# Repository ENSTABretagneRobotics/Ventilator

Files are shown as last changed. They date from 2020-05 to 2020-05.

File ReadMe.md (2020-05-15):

# High flow oxygenation and ventilator prototype

This repository contains the software and CAD parts of a simple ventilator prototype made at ENSTA Bretagne in April-May 2020, with the help of Pr E. L'Her from Brest CHRU. Details on the design are available [here](https://www.ensta-bretagne.fr/lebars/Share/ventilator_prototype.pdf). The demo of the high flow oxygenation mode can be seen [is this video](https://youtu.be/vLqbTjcoQs8), the patient-triggered assistance mode is tested [there](https://youtu.be/5zMtCWrAtUk), and other random tests are made [here](https://youtu.be/ZAll08g8yRg).

Ventilator picture

See [this document](https://www.ensta-bretagne.fr/lebars/Share/ventilator_devices.pdf) for more information about the electronics architecture, check the configuration instructions in the top of `main.py` and run the code with `sudo -E python3 main.py & python3 gui.py`.

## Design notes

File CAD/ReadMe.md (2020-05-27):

It is possible to view the full CAD model using this link: https://autode.sk/3bMTDJe

The pieces are separated by the method of production into:
- To print
- To machine

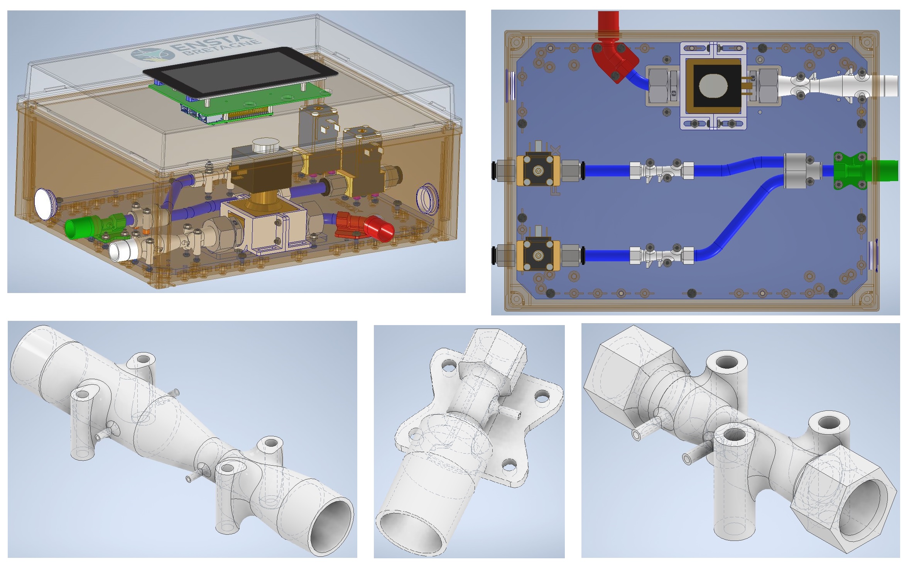
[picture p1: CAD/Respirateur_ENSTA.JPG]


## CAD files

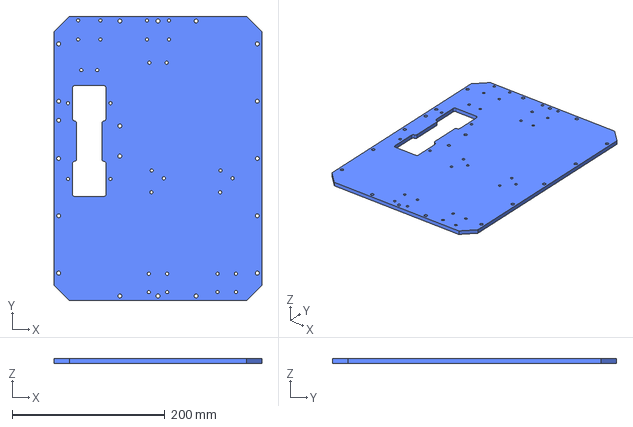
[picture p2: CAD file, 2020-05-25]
CAD/ToMachine/Base_Sheet.stp
271.8 x 371.8 x 6.00 mm

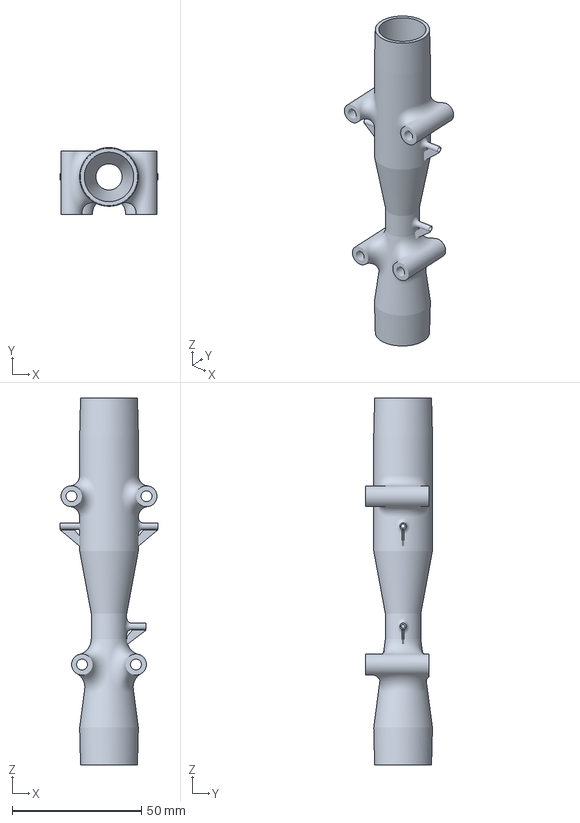
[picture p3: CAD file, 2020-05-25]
CAD/ToPrint/HighDefNozzle/3MF/UM3E_Venturi_1.5_Out.3mf
37.7 x 25.9 x 141.8 mm

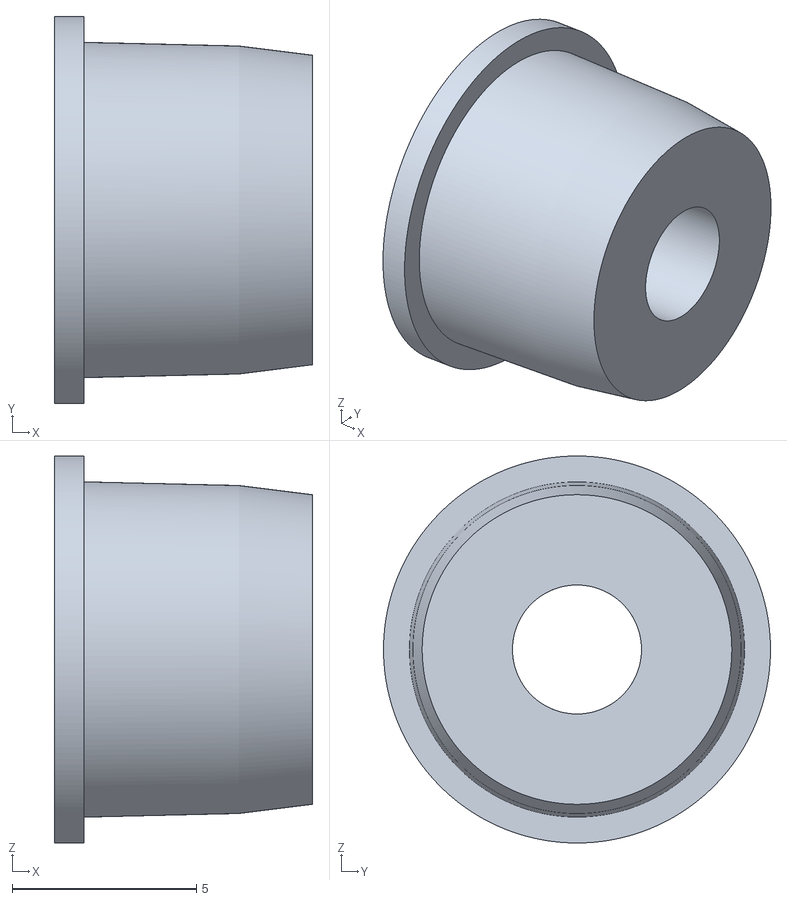
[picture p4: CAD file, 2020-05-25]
CAD/ToPrint/HighDefNozzle/STL/Orifice_3.50mm.stl
7.00 x 10.5 x 10.5

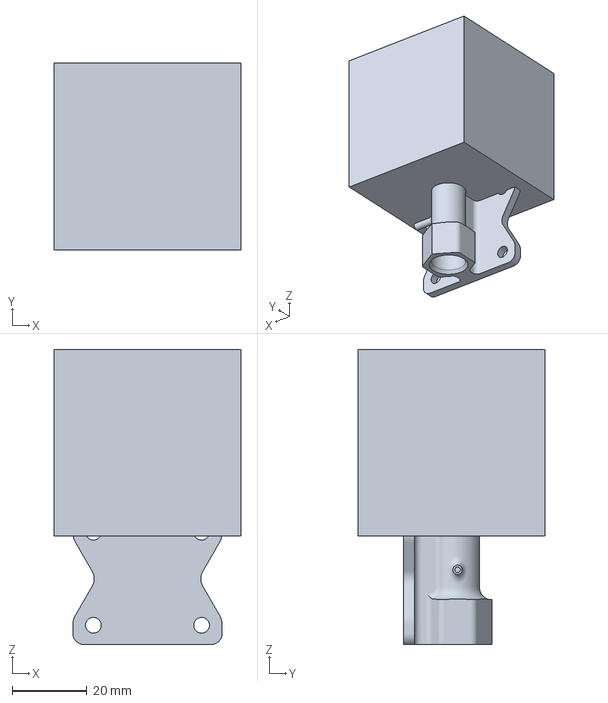
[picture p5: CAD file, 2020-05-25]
CAD/ToPrint/NormalNozzle/3MF/Adapter_12x22mm_v2.3mf
50.0 x 50.0 x 79.0 mm

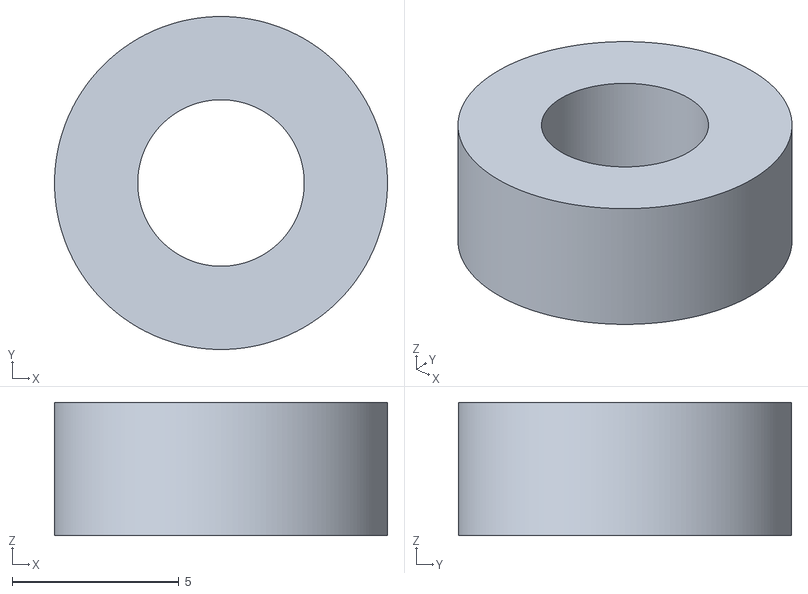
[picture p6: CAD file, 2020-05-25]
CAD/ToPrint/NormalNozzle/STL/Spacer_V2.stl
10.0 x 10.0 x 4.00

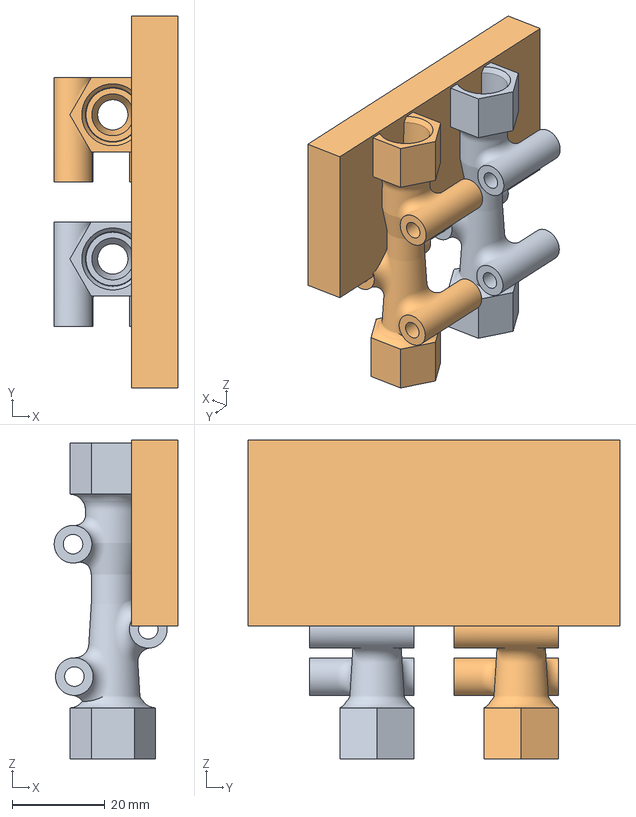
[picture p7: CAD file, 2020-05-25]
CAD/ToPrint/HighDefNozzle/3MF/UM3E_Venturi_1.3c_2x.3mf
26.6 x 80.0 x 68.6 mm
Venturi_1.3c.stl
Venturi_1.3c.stl(1)

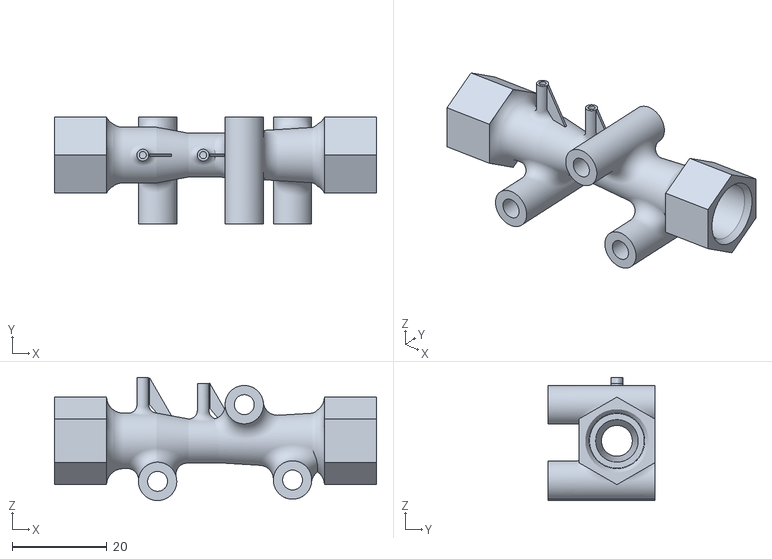
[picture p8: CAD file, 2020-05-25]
CAD/ToPrint/HighDefNozzle/STL/Venturi_1.3c.stl
67.9 x 22.5 x 26.0

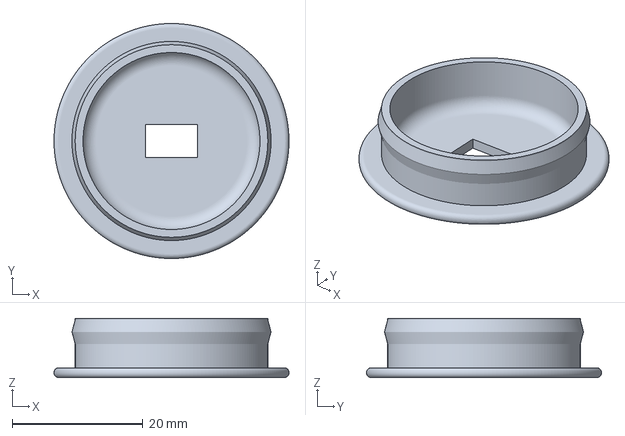
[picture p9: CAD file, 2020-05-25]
CAD/ToPrint/NormalNozzle/3MF/UM3E_Tap_Box_V2.3mf
36.0 x 36.0 x 9.07 mm

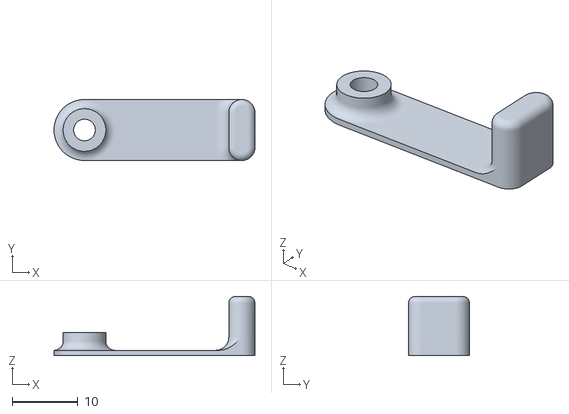
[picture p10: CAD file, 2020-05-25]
CAD/ToPrint/NormalNozzle/STL/Screen-Locker_V2.stl
30.6 x 9.30 x 9.00

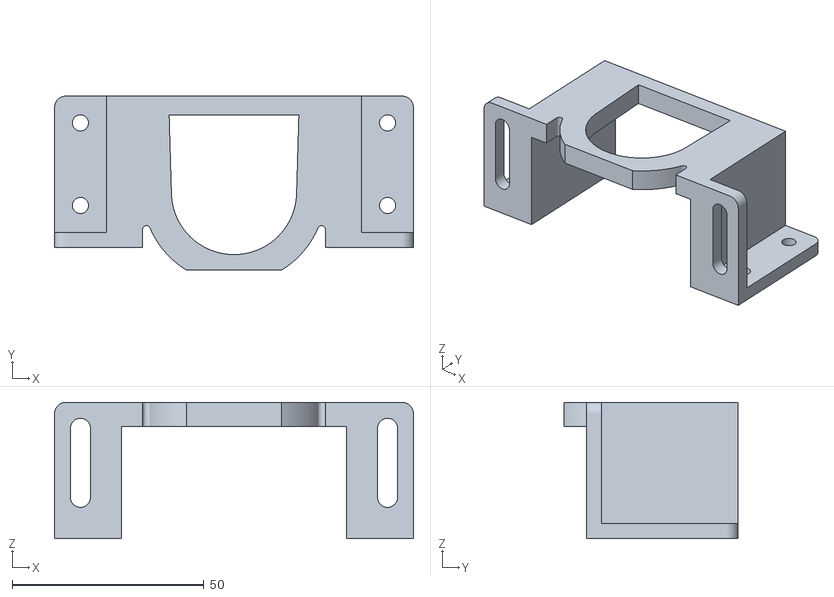
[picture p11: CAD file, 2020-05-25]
CAD/ToPrint/NormalNozzle/STL/SCB210C035_Support.stl
93.5 x 45.3 x 35.5

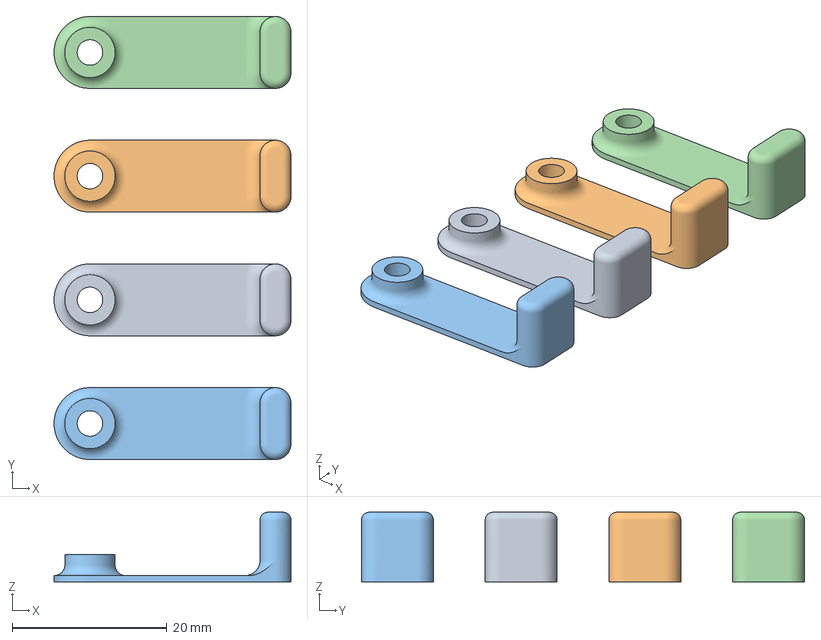
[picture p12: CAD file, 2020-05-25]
CAD/ToPrint/NormalNozzle/3MF/UM3E_Screen-Locker_V2.3mf
30.6 x 57.3 x 9.00 mm
Screen-Locker_V2.stl
Screen-Locker_V2.stl(1)
Screen-Locker_V2.stl(2)
Screen-Locker_V2.stl(3)

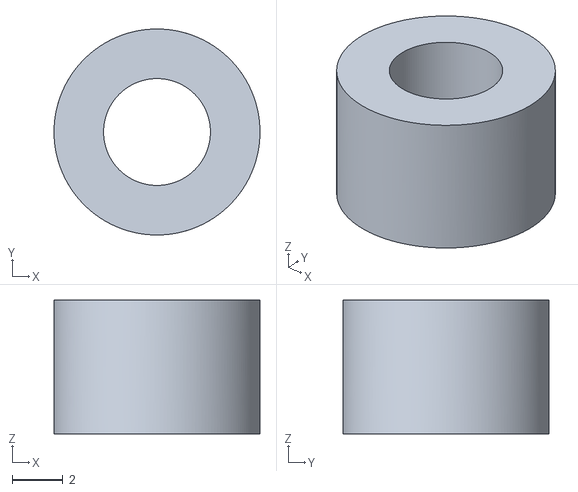
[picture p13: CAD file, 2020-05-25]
CAD/ToPrint/NormalNozzle/STL/Ring_5.25mm.stl
8.10 x 8.10 x 5.25

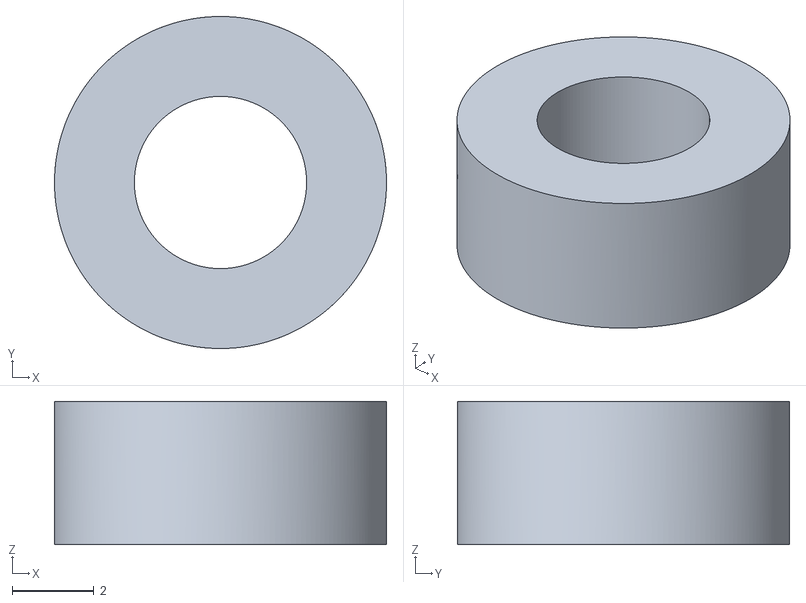
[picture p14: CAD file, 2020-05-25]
CAD/ToPrint/NormalNozzle/STL/Ring_3.5mm.stl
8.10 x 8.10 x 3.50

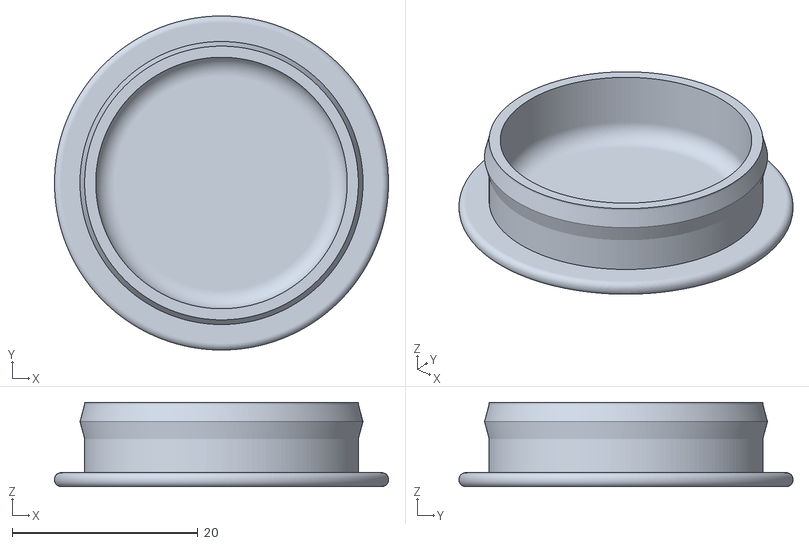
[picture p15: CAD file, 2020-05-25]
CAD/ToPrint/NormalNozzle/STL/Tap_Box.stl
36.0 x 36.0 x 9.07

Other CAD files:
CAD/ToPrint/HighDefNozzle/3MF/UM3E_Orifice_3.50mm.3mf
CAD/ToPrint/HighDefNozzle/STL/Venturi_1.5_Out.stl
CAD/ToPrint/NormalNozzle/3MF/UM3E_Spacer_V2.3mf
CAD/ToPrint/NormalNozzle/STL/Adapter_12x22mm_45deg.stl
CAD/ToPrint/NormalNozzle/STL/Adapter_12x22mm_v2.stl

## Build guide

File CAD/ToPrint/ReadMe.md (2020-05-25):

The printed parts were obtained using the FDM method through an Ultimaker 3 Extended printer using Ultimaker CURA as the slicer.

This folder contains the parts that have to be 3D printed. They are divided into two types depending on the required accuracy:
- Normal nozzle diameter: 0.40 mm
- High-definition nozzle diameter: 0.25 mm

ATTENTION: STL files do not show the parts in the correct printing orientation. To know the correct part orientation and printing configurations check 3MF files in CURA slicer.

(CURA slicer is available in https://ultimaker.com/software/ultimaker-cura)

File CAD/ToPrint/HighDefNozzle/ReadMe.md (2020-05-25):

High-definition diameter: 0.20 or 0.25 mm

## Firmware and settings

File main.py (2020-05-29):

#!/usr/bin/python

from __future__ import division, print_function
import ms5837 # From https://github.com/bluerobotics/ms5837-python
import rsc # From https://github.com/tin-/ascp
import hsc
import numpy as np
import math
import sys
import os
import time
import threading
import signal
from timeit import default_timer as timer
from common import *

#sudo apt-get install python-smbus python-spidev python-pyqtgraph
# or
#sudo pip install smbus
#sudo pip install spidev
#sudo pip install pyqtgraph
# if it did not work and/or try also with python3 and pip3.
# Raspberry Pi 4 configuration (GPIO that will be used : 0 for PWM expiration 
# valve, 1, 2, 3, 14, 15 for SPI3 Honeywell RSC for flow (expiration), 4, 5
# for I2C3 Honeywell HSC (expiration)[, Bar02 (room), 6 for digital
# output inspiration valve], 7, 8, 9, 10, 11 for SPI0 Honeywell RSC for flow 
# (air), 12, 13 for PWM O2 and air valves, 16 for 
# digital input UP button, 17 for digital input DOWN button, 18, 19, 20, 21, 27
# for SPI6 Honeywell RSC for flow (O2), 22, 23 for I2C6 Honeywell HSC 
# (inspiration)[, Bar02 (inspiration), RTC clock], 24 for digital input
# SELECT button, 25 for POWER button, 26 for PWM buzzer)
#sudo nano /boot/config.txt
# Add/modify in /boot/config.txt (SPI6 might appear as 4, check /dev...)
#enable_uart=0
#dtparam=i2c_arm=on
#dtoverlay=i2c1,pins_44_45
#dtoverlay=i2c-gpio,bus=3,i2c_gpio_delay_us=1,i2c_gpio_sda=4,i2c_gpio_scl=5
#dtoverlay=i2c-gpio,bus=6,i2c_gpio_delay_us=1,i2c_gpio_sda=22,i2c_gpio_scl=23
#dtparam=spi=on
#dtoverlay=spi3-2cs,cs0_pin=14,cs1_pin=15
#dtoverlay=spi6-2cs
#dtoverlay=gpio-shutdown,gpio_pin=25,active_low=1,gpio_pull=up
# Disable touch screen sleep (see https://www.raspberrypi.org/forums/viewtopic.php?t=255163)
#sudo nano /etc/xdg/lxsession/LXDE-pi/autostart
#@xset s off
#@xset -dpms
# Then reboot and
#sudo -E python main.py & python gui.py

# Parameters
###############################################################################
# User parameters
mode = 0 # 0 : ventilator, 1 : ventilator in assistance mode, 2 : only O2:Air mix
flow_control = 40 # In L/min, >= flow_control_max means no limit...
O2_percent = 50 # In %, 0 means no pure O2 will be added to air, 100 means no air, ignored if flow_control >= flow_control_max...
ramp = 10 # In % of the inspiration time, to increase progressively flow and avoid pressure peak just due to strong and fast flow...
Ppeak = 30 # In mbar (= approx. cmH2O)
PEEP = 5 # In mbar (= approx. cmH2O)
respi_rate = 20 # In breaths/min
inspi_percent = 33 # Inspiration time in % of cycle time
# User advanced parameters
PEEP_dec_rate = 100 # In %, to limit the maximum expiration flow before reaching the PEEP
PEEP_tuning = 100 # In %, to tune the expiration flow when maintaining the PEEP
Fl_PEEP = 100 # In % of flow_control, to help detecting inspiration after reaching the PEEP
O2_PEEP = 100 # In % of O2_percent, to help detecting inspiration after reaching the PEEP
PEEP_inspi_detection_delta = 2.5 # In mbar (= approx. cmH2O)
vol_inspi_detection_delta = 15 # In ml
inspi_detection_delta_duration = 250 # In ms
flow_thresh = 4 # To avoid noise in volume computation, in L/min
# Advanced parameters
mode_step = 1
mode_min = 0
mode_max = 2
flow_control_step = 2
flow_control_min = 0
flow_control_max = 300
O2_percent_step = 1
O2_percent_min = 0
O2_percent_max = 100
ramp_step = 1
ramp_min = 0
ramp_max = 100
Ppeak_step = 1
Ppeak_min = 0
Ppeak_max = 150
PEEP_step = 1
PEEP_min = 0
PEEP_max = 150
respi_rate_step = 1
respi_rate_min = 1
respi_rate_max = 100
inspi_percent_step = 1
inspi_percent_min = 0
inspi_percent_max = 100
PEEP_dec_rate_step = 2
PEEP_dec_rate_min = 1
PEEP_dec_rate_max = 100
PEEP_tuning_step = 2
PEEP_tuning_min = 1
PEEP_tuning_max = 100
Fl_PEEP_step = 5
Fl_PEEP_min = 0
Fl_PEEP_max = 1000
O2_PEEP_step = 5
O2_PEEP_min = 0
O2_PEEP_max = 1000
PEEP_inspi_detection_delta_step = 0.1
PEEP_inspi_detection_delta_min = 0
PEEP_inspi_detection_delta_max = 50
vol_inspi_detection_delta_step = 1
vol_inspi_detection_delta_min = 0
vol_inspi_detection_delta_max = 100
inspi_detection_delta_duration_step = 10
inspi_detection_delta_duration_min = 0
inspi_detection_delta_duration_max = 1000
flow_thresh_step = 0.25
flow_thresh_min = 0
flow_thresh_max = 50
enable_alarms = True
enable_buzzer = True
enable_p_ms5837 = False
enable_p0_ms5837 = False
enable_p_inspi_hsc = True
enable_p_expi_hsc = True
enable_air_rsc = True
enable_expi_rsc = True
enable_O2_rsc = True
rho0_air = 1.292 # In kg/m3 at 0 C
rho0_expi = 1.292 # In kg/m3 at 0 C
#rho0_O2 = 1.428 # In kg/m3 at 0 C
rho0_O2 = 1.292 # In kg/m3 at 0 C
#R1_air = 0.019100/2.0 # In m
R1_air = 0.009000/2.0 # In m
#R2_air = 0.011651/2.0 # In m
R2_air = 0.006500/2.0 # In m
R1_expi = 0.019100/2.0 # In m
#R1_expi = 0.009000/2.0 # In m
#R2_expi = 0.011651/2.0 # In m
R2_expi = 0.010100/2.0 # In m
#R2_expi = 0.006500/2.0 # In m
#R2_expi = 0.008000/2.0 # In m
#R1_O2 = 0.019100/2.0 # In m
R1_O2 = 0.009000/2.0 # In m
#R2_O2 = 0.011651/2.0 # In m
R2_O2 = 0.006500/2.0 # In m
rho_air = rho0_air
rho_expi = rho0_expi
rho_O2 = rho0_O2
A1_air = math.pi*R1_air**2 # In m2
A2_air = math.pi*R2_air**2 # In m2
A1_expi = math.pi*R1_expi**2 # In m2
A2_expi = math.pi*R2_expi**2 # In m2
A1_O2 = math.pi*R1_O2**2 # In m2
A2_O2 = math.pi*R2_O2**2 # In m2
speed_rsc = 175 # In SPS
delay_rsc = 0.010 # In s
coef_filter_rsc = 0.95
nb_count_auto_zero_filter_rsc = 100 # 100
nb_count_offset_filter_rsc = 100 # 100
valves_pwm_freq = 1200 # In Hz
valves_init = 50
valves_closed = 10 # Should be <= 99
valves_delay = 0.020 # In s
P_err = 50 # In mbar (= approx. cmH2O)
P_absolute_min = -10 # In mbar (= approx. cmH2O)
P_absolute_max = 159 # In mbar (= approx. cmH2O)
coef_offset_filter_flow = 0.99
coef_filter_flow = 0.0
positive_filter_flow = True
flow_control_PEEP = flow_control*Fl_PEEP*0.01
flow_control_pressure_excess = flow_control
flow_control_PEEP_pressure_excess = flow_control_PEEP
err_pressure_PEEP_thresh = 0.5 # In mbar (= approx. cmH2O)
coef_PEEP_pressure_control_valve_expi = 2.0
coef_PEEP_flow_control_valve_expi = 0.0
coef_PEEP_pressure_control_valve_air = 0.0
coef_PEEP_pressure_control_valve_O2 = 0.0
coef_PEEP_flow_control_valve_air = 2.0
coef_PEEP_flow_control_valve_O2 = 2.0
coef_pressure_excess = 8.0
coef_flow_control_valve_air = 2.0
coef_flow_control_valve_O2 = 2.0
debug = False
###############################################################################

alarms = 0

os.system('pigpiod -x 0x0FFFFFFF') # To be able to use GPIO 0 and 1 also...
time.sleep(0.2)
import pigpio
pi = pigpio.pi()
if not pi.connected:
    print('Unable to connect to pigpio')
    exit(1)
print('pigpio connected')

# Software PWM init for buzzer
if enable_buzzer:
    buz_pin = 26
    pi.set_mode(buz_pin, pigpio.OUTPUT)
    pi.set_PWM_frequency(buz_pin, 4000)
    pi.set_PWM_dutycycle(buz_pin, 128) # Startup beep...

# Other PWM init
valve_air_pin = 12
if (flow_control < flow_control_max): valve_air_val_max = valves_init # Min > 0 to not always disable proportional valves control...
else: valve_air_val_max = 100
valve_air_val_max_closed = valve_air_val_max
valve_air_val_max_PEEP = valves_init
valve_air_val = 0
valve_air_val = min(100, max(0, valve_air_val))
valve_O2_pin = 13
if (flow_control < flow_control_max): valve_O2_val_max = valves_init # Min > 0 to not always disable proportional valves control...
else: valve_O2_val_max = 100
valve_O2_val_max_closed = valve_O2_val_max
valve_O2_val_max_PEEP = valves_init
valve_O2_val = 0
valve_O2_val = min(100, max(0, valve_O2_val))
pi.set_mode(valve_air_pin, pigpio.OUTPUT)
pi.set_PWM_frequency(valve_air_pin, valves_pwm_freq)
pi.set_PWM_dutycycle(valve_air_pin, int(min(255, max(0, 255*valve_air_val/100))))
pi.set_mode(valve_O2_pin, pigpio.OUTPUT)
pi.set_PWM_frequency(valve_O2_pin, valves_pwm_freq)
pi.set_PWM_dutycycle(valve_O2_pin, int(min(255, max(0, 255*valve_O2_val/100))))

# Digital outputs (valves)
valve_expi_pin = 0
valve_expi_val_max_PEEP = PEEP_dec_rate
valve_expi_val = 0
valve_expi_val = min(100, max(0, valve_expi_val))
pi.set_mode(valve_expi_pin, pigpio.OUTPUT)
pi.set_PWM_frequency(valve_expi_pin, valves_pwm_freq)
pi.set_PWM_dutycycle(valve_expi_pin, int(min(255, max(0, 255-255*valve_expi_val/100)))) 

# Digital inputs (buttons)
select = -1 # Index of the selected parameter that should be changed by up/down buttons
parameters = ['mode', 'flow_control', 'O2_percent', 'ramp', 'Ppeak', 'PEEP', 'respi_rate', 'inspi_percent', 
              'PEEP_dec_rate', 'PEEP_tuning', 'Fl_PEEP', 'O2_PEEP', 'PEEP_inspi_detection_delta', 'vol_inspi_detection_delta', 'inspi_detection_delta_duration', 'flow_thresh']
select_button_pin = 24
pi.set_mode(select_button_pin, pigpio.INPUT)
pi.set_pull_up_down(select_button_pin, pigpio.PUD_UP)
select_button_val = pi.read(select_button_pin)
select_button_val_prev = select_button_val
up_button_pin = 16
pi.set_mode(up_button_pin, pigpio.INPUT)
pi.set_pull_up_down(up_button_pin, pigpio.PUD_UP)
up_button_val = pi.read(up_button_pin)
up_button_val_prev = up_button_val
down_button_pin = 17
pi.set_mode(down_button_pin, pigpio.INPUT)
pi.set_pull_up_down(down_button_pin, pigpio.PUD_UP)
down_button_val = pi.read(down_button_pin)
down_button_val_prev = down_button_val

# Bar02, HSC
if enable_p_ms5837:
    p_ms5837 = ms5837.MS5837_02BA(bus = 6)
    try:
        if not p_ms5837.init():
            print('P sensor could not be initialized')
            time.sleep(0.1)
            if not p_ms5837.init():
                print('P sensor could not be initialized')
                exit(1)
    except:
        print('P sensor could not be initialized')
        time.sleep(0.1)
        if not p_ms5837.init():
            print('P sensor could not be initialized')
            exit(1)
if enable_p0_ms5837:
    p0_ms5837 = ms5837.MS5837_02BA(bus = 3)
    try:
        if not p0_ms5837.init():
            print('P0 sensor could not be initialized')
            time.sleep(0.1)
            if not p0_ms5837.init():
                print('P0 sensor could not be initialized')
                exit(1)
    except:
        print('P0 sensor could not be initialized')
        time.sleep(0.1)
        if not p0_ms5837.init():
            print('P0 sensor could not be initialized')
            exit(1)
if enable_p_inspi_hsc:
    try:
        p_inspi_hsc = hsc.HHSC(bus = 6, addr = 0x48, min_pressure = -160.0, max_pressure = 160.0, unit = 'mbar', transfer = 'A')
    except:
        print('HSC I sensor could not be initialized')
        time.sleep(0.1)
        try:
            p_inspi_hsc = hsc.HHSC(bus = 6, addr = 0x48, min_pressure = -160.0, max_pressure = 160.0, unit = 'mbar', transfer = 'A')
        except:
            print('HSC I sensor could not be initialized')
            exit(1)
if enable_p_expi_hsc:
    try:
        p_expi_hsc = hsc.HHSC(bus = 3, addr = 0x48, min_pressure = -160.0, max_pressure = 160.0, unit = 'mbar', transfer = 'A')
    except:
        print('HSC E sensor could not be initialized')
        time.sleep(0.1)
        try:
            p_expi_hsc = hsc.HHSC(bus = 3, addr = 0x48, min_pressure = -160.0, max_pressure = 160.0, unit = 'mbar', transfer = 'A')
        except:
            print('HSC E sensor could not be initialized')
            exit(1)
# The very first pressure measurements might be wrong...
i = 0
while (i < 5):
    if enable_p_ms5837:
        if not p_ms5837.read(ms5837.OSR_256):
            print('P sensor read failed!')
            time.sleep(0.1)
    if enable_p0_ms5837:
        if not p0_ms5837.read(ms5837.OSR_256):
            print('P0 sensor read failed!')
            time.sleep(0.1)
    if enable_p_inspi_hsc:
        try:
            p_diff_inspi_hsc, temp_inspi_hsc = p_inspi_hsc.read()
        except:
            print('HSC I sensor read failed!')
            time.sleep(0.1)
    if enable_p_expi_hsc:
        try:
            p_diff_expi_hsc, temp_expi_hsc = p_expi_hsc.read()
        except:
            print('HSC E sensor read failed!')
            time.sleep(0.1)
    i = i+1

# Honeywell RSC
pressure_air, temperature_air, flow_air, flow_filtered_air, vol_air, pressure_offset_air, flow_offset_air = 0, 25, 0, 0, 0, 0, 0
pressure_expi, temperature_expi, flow_expi, flow_filtered_expi, vol_expi, pressure_offset_expi, flow_offset_expi = 0, 25, 0, 0, 0, 0, 0
pressure_O2, temperature_O2, flow_O2, flow_filtered_O2, vol_O2, pressure_offset_O2, flow_offset_O2 = 0, 25, 0, 0, 0, 0, 0
if enable_air_rsc: 
    flow_air_rsc = rsc.HRSC(spi_bus = 0)
    flow_air_rsc.sensor_info()
    flow_air_rsc.reset()
if enable_expi_rsc: 
    flow_expi_rsc = rsc.HRSC(spi_bus = 3)
    flow_expi_rsc.sensor_info()
    flow_expi_rsc.reset()
if enable_O2_rsc: 
    flow_O2_rsc = rsc.HRSC(spi_bus = 4)
    flow_O2_rsc.sensor_info()
    flow_O2_rsc.reset()
time.sleep(0.005)
if enable_air_rsc: 
    flow_air_rsc.adc_configure()
    flow_air_rsc.set_speed(speed_rsc)
if enable_expi_rsc: 
    flow_expi_rsc.adc_configure()
    flow_expi_rsc.set_speed(speed_rsc)
if enable_O2_rsc: 
    flow_O2_rsc.adc_configure()
    flow_O2_rsc.set_speed(speed_rsc)
time.sleep(0.005)
if enable_air_rsc: 
    flow_air_rsc.pressure_request()
if enable_expi_rsc: 
    flow_expi_rsc.pressure_request()
if enable_O2_rsc: 
    flow_O2_rsc.pressure_request()
time.sleep(delay_rsc)
if enable_air_rsc: 
    raw_pressure_air = flow_air_rsc.pressure_reply()
    flow_air_rsc.temperature_request()
if enable_expi_rsc: 
    raw_pressure_expi = flow_expi_rsc.pressure_reply()
    flow_expi_rsc.temperature_request()
if enable_O2_rsc: 
    raw_pressure_O2 = flow_O2_rsc.pressure_reply()
    flow_O2_rsc.temperature_request()
time.sleep(delay_rsc)
if enable_air_rsc: 
    raw_temperature_air = flow_air_rsc.temperature_reply()
    raw_zero_pressure_air = raw_pressure_air
    raw_zero_temperature_air = raw_temperature_air
    pressure_air, temperature_air = flow_air_rsc.comp_readings(raw_pressure_air, raw_temperature_air)
    pressure_air = flow_air_rsc.conv_pressure_to_mbar(pressure_air)
    pressure_offset_air = pressure_air
if enable_expi_rsc: 
    raw_temperature_expi = flow_expi_rsc.temperature_reply()
    raw_zero_pressure_expi = raw_pressure_expi
    raw_zero_temperature_expi = raw_temperature_expi
    pressure_expi, temperature_expi = flow_expi_rsc.comp_readings(raw_pressure_expi, raw_temperature_expi)
    pressure_expi = flow_expi_rsc.conv_pressure_to_mbar(pressure_expi)
    pressure_offset_expi = pressure_expi
if enable_O2_rsc: 
    raw_temperature_O2 = flow_O2_rsc.temperature_reply()
    raw_zero_pressure_O2 = raw_pressure_O2
    raw_zero_temperature_O2 = raw_temperature_O2
    pressure_O2, temperature_O2 = flow_O2_rsc.comp_readings(raw_pressure_O2, raw_temperature_O2)
    pressure_O2 = flow_O2_rsc.conv_pressure_to_mbar(pressure_O2)
    pressure_offset_O2 = pressure_O2
# Auto-zero filter proposed by the documentation in the beginning (with valves closed)...
i = 0
while (i < nb_count_auto_zero_filter_rsc):
    if enable_air_rsc: 
        flow_air_rsc.pressure_request()
    if enable_expi_rsc: 
        flow_expi_rsc.pressure_request()
    if enable_O2_rsc: 
        flow_O2_rsc.pressure_request()
    time.sleep(delay_rsc)
    if enable_air_rsc: 
        raw_pressure_air = flow_air_rsc.pressure_reply()
        flow_air_rsc.temperature_request()
    if enable_expi_rsc: 
        raw_pressure_expi = flow_expi_rsc.pressure_reply()
        flow_expi_rsc.temperature_request()
    if enable_O2_rsc: 
        raw_pressure_O2 = flow_O2_rsc.pressure_reply()
        flow_O2_rsc.temperature_request()
    time.sleep(delay_rsc)
    if enable_air_rsc: 
        raw_temperature_air = flow_air_rsc.temperature_reply()
        raw_zero_pressure_air = (1-coef_filter_rsc)*raw_pressure_air+coef_filter_rsc*raw_zero_pressure_air
        raw_zero_temperature_air = (1-coef_filter_rsc)*raw_temperature_air+coef_filter_rsc*raw_zero_temperature_air
    if enable_expi_rsc: 
        raw_temperature_expi = flow_expi_rsc.temperature_reply()
        raw_zero_pressure_expi = (1-coef_filter_rsc)*raw_pressure_expi+coef_filter_rsc*raw_zero_pressure_expi
        raw_zero_temperature_expi = (1-coef_filter_rsc)*raw_temperature_expi+coef_filter_rsc*raw_zero_temperature_expi
    if enable_O2_rsc: 
        raw_temperature_O2 = flow_O2_rsc.temperature_reply()
        raw_zero_pressure_O2 = (1-coef_filter_rsc)*raw_pressure_O2+coef_filter_rsc*raw_zero_pressure_O2
        raw_zero_temperature_O2 = (1-coef_filter_rsc)*raw_temperature_O2+coef_filter_rsc*raw_zero_temperature_O2
    i = i+1
# Store auto-zero info...
if (nb_count_auto_zero_filter_rsc > 0):
    if enable_air_rsc: 
        flow_air_rsc.comp_auto_zero(raw_zero_pressure_air, raw_zero_temperature_air)
    if enable_expi_rsc: 
        flow_expi_rsc.comp_auto_zero(raw_zero_pressure_expi, raw_zero_temperature_expi)
    if enable_O2_rsc: 
        flow_O2_rsc.comp_auto_zero(raw_zero_pressure_O2, raw_zero_temperature_O2)
# Additional filter to estimate the offset in the beginning (with valves closed)...
i = 0
while (i < nb_count_offset_filter_rsc):
    if enable_air_rsc: 
        flow_air_rsc.pressure_request()
    if enable_expi_rsc: 
        flow_expi_rsc.pressure_request()
    if enable_O2_rsc: 
        flow_O2_rsc.pressure_request()
    time.sleep(delay_rsc)
    if enable_air_rsc: 
        raw_pressure_air = flow_air_rsc.pressure_reply()
        flow_air_rsc.temperature_request()
    if enable_expi_rsc: 
        raw_pressure_expi = flow_expi_rsc.pressure_reply()
        flow_expi_rsc.temperature_request()
    if enable_O2_rsc: 
        raw_pressure_O2 = flow_O2_rsc.pressure_reply()
        flow_O2_rsc.temperature_request()
    time.sleep(delay_rsc)
    if enable_air_rsc: 
        raw_temperature_air = flow_air_rsc.temperature_reply()
        pressure_air, temperature_air = flow_air_rsc.comp_readings(raw_pressure_air, raw_temperature_air)
        pressure_air = flow_air_rsc.conv_pressure_to_mbar(pressure_air)
        pressure_offset_air = (1-coef_filter_rsc)*pressure_air+coef_filter_rsc*pressure_offset_air
    if enable_expi_rsc: 
        raw_temperature_expi = flow_expi_rsc.temperature_reply()
        pressure_expi, temperature_expi = flow_expi_rsc.comp_readings(raw_pressure_expi, raw_temperature_expi)
        pressure_expi = flow_expi_rsc.conv_pressure_to_mbar(pressure_expi)
        pressure_offset_expi = (1-coef_filter_rsc)*pressure_expi+coef_filter_rsc*pressure_offset_expi
    if enable_O2_rsc: 
        raw_temperature_O2 = flow_O2_rsc.temperature_reply()
        pressure_O2, temperature_O2 = flow_O2_rsc.comp_readings(raw_pressure_O2, raw_temperature_O2)
        pressure_O2 = flow_O2_rsc.conv_pressure_to_mbar(pressure_O2)
        pressure_offset_O2 = (1-coef_filter_rsc)*pressure_O2+coef_filter_rsc*pressure_offset_O2
    i = i+1
if (nb_count_offset_filter_rsc <= 0):
    pressure_offset_air = 0
    pressure_offset_expi = 0
    pressure_offset_O2 = 0

respi_rate_converted = respi_rate*(1.0/60.0) # In breaths/s
cycle_duration = 1.0/respi_rate_converted
inspi_duration = inspi_percent*0.01*cycle_duration
expi_duration = cycle_duration-inspi_duration

t = timer()
t_prev = t
dt = t-t_prev
t0 = t
t_cycle_start = t
p0 = 1000
p = 1000
p_e = 1000
if enable_p_ms5837: p = p_ms5837.pressure()
if enable_p_inspi_hsc: p = p0+p_diff_inspi_hsc
if enable_p_expi_hsc: p_e = p0+p_diff_expi_hsc
p_prev = p
p_cycle_start = p
p0 = p
if enable_p0_ms5837: p0 = p0_ms5837.pressure() 
temperature = 25
temperature_e = 25
if enable_p_ms5837: temperature = p_ms5837.temperature()
if enable_p_inspi_hsc: temperature = temp_inspi_hsc
if enable_p_expi_hsc: temperature_e = temp_expi_hsc
temperature0 = temperature
if enable_p0_ms5837: temperature0 = p0_ms5837.temperature()
Ppeak_reached = False
PEEP_reached = False
inspi_end = False
force_new_cycle = False
t_hist = []
flow_hist = []
vol_hist = []

t_last_not_all_valves_closed = t0
t_all_valves_closed = t0
t_valve_air_closed = t0
t_valve_O2_closed = t0
t_valve_expi_closed = t0
t_alarms = t0

# Stop the startup beep
if enable_buzzer: pi.set_PWM_dutycycle(buz_pin, 0)

# File errors are not critical...
try:
    file = open('data.csv', 'a')
    file.write('t (in s);t0 (in s);p0 (in mbar);temperature0 (in C);p (in mbar);temperature (in C);p_e (in mbar);temperature_e (in C);alarms;select;'
                'mode;flow_control (in L/min);O2_percent (in %);ramp (in %);Ppeak (in mbar);PEEP (in mbar);respi_rate (in breaths/min);inspi_percent (in %);'
                'PEEP_dec_rate (in %);PEEP_tuning (in %);Fl_PEEP (in %);O2_PEEP (in %);PEEP_inspi_detection_delta (in mbar);vol_inspi_detection_delta (in ml);inspi_detection_delta_duration (in ms);flow_thresh (in L/min);'
                'valve_air_val;valve_O2_val;valve_expi_val;'
                'pressure_air (in mbar);pressure_expi (in mbar);pressure_O2 (in mbar);temperature_air (in C);temperature_expi (in C);temperature_O2 (in C);'
                'flow_air (in L/min);flow_expi (in L/min);flow_O2 (in L/min);flow_filtered_air (in L/min);flow_filtered_expi (in L/min);flow_filtered_O2 (in L/min);vol_air (in L);vol_expi (in L);vol_O2 (in L);\n')
except:
    if enable_alarms:
        t_alarms = t
        alarms = alarms | OS_ALARM

bExit = False

def signal_handler(sig, frame):
    global bExit
    #signal.signal(signal.SIGINT, signal.SIG_IGN) # To avoid interruption by other CTRL+C...
    bExit = True

signal.signal(signal.SIGINT, signal_handler) # To be able to put actuators in a safe state when using CTRL+C

# Divisions by 0, NAN, INF, int divisions...?
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

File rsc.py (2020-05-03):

#!/usr/bin/python

# Copyright (c) 2017 xDevs.com
# Author: Illya Tsemenko
#
# Based on the RSC datasheet
#
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
from __future__ import division, print_function
import time
import struct
try:
    import spidev
except:
    print('Try sudo apt-get install python-spidev')

# HRSC Commands
HRSC_SINGLE_READ_CMD = 0xAA
HRSC_AVG2_READ_CMD   = 0xAC
HRSC_AVG4_READ_CMD   = 0xAD
HRSC_AVG8_READ_CMD   = 0xAE
HRSC_AVG16_READ_CMD  = 0xAF

# HRSC Status bits
HRSC_STS_ZERO          = 0b10000000
HRSC_STS_PWRON         = 0b01000000
HRSC_STS_BUSY          = 0b00100000
HRSC_STS_MODE          = 0b00011000
HRSC_STS_EEPROM_CHKERR = 0b00000100
HRSC_STS_SNSCFG        = 0b00000010
HRSC_STS_ALUERR        = 0b00000001

HRSC_EAD_EEPROM_LSB    = 0x03
HRSC_EAD_EEPROM_MSB    = 0x0B
HRSC_ADC_WREG          = 0x40 
HRSC_ADC_RESET         = 0x06

#Prange   = 0.0                  # Pressure range from ROM 
#Pmin     = 0.0                  # Pressure offset from ROM
#EngUnit  = 0.0                  # Engineering units from ROM
#Praw     = 0.0                  # Uncompensated pressure from ADC
#Traw     = 0.0                  # Uncompensated temperature from ADC
#Pint1    = 0.0                  # Intermediate value 1
#Pint2    = 0.0                  # Intermediate value 2
#Pcomp_fs = 0.0                  # Compensated output pressure 
#Pcomp    = 0.0                  # Compensated output pressure, in units

class HRSC(object):

    def __init__(self, spi_bus = 0, spi_speed_hz = 1250000, spi_max_speed_hz = 1250000, force_spi_mode = True, EE_spi_mode = 0b00, alt_spi_cs0 = -1, alt_spi_cs1 = -1, **kwargs):
        # Create device.
        self.spi_bus = spi_bus
        self.spi_speed_hz = spi_speed_hz
        self.spi_max_speed_hz = spi_max_speed_hz
        self.force_spi_mode = force_spi_mode
        self.EE_spi_mode = EE_spi_mode
        self.alt_spi_cs0 = alt_spi_cs0
        self.alt_spi_cs1 = alt_spi_cs1
        self.spi = spidev.SpiDev()
        self.spi.open(self.spi_bus, 1)
        self.spi.max_speed_hz = self.spi_max_speed_hz
        if self.force_spi_mode: self.spi.mode = self.EE_spi_mode
        if ((self.alt_spi_cs0 >= 0) or (self.alt_spi_cs1 >= 0)): import RPi.GPIO as GPIO
        if (self.alt_spi_cs1 >= 0): GPIO.setup(self.alt_spi_cs1, GPIO.OUT, initial = GPIO.LOW)
        if (self.alt_spi_cs0 >= 0): GPIO.setup(self.alt_spi_cs0, GPIO.OUT, initial = GPIO.HIGH)
        self.spi.close()
        self.spi.open(self.spi_bus, 0)
        self.spi.max_speed_hz = self.spi_max_speed_hz
        if self.force_spi_mode: self.spi.mode = 0b01
        if (self.alt_spi_cs0 >= 0): GPIO.setup(self.alt_spi_cs0, GPIO.OUT, initial = GPIO.LOW)
        if (self.alt_spi_cs1 >= 0): GPIO.setup(self.alt_spi_cs1, GPIO.OUT, initial = GPIO.HIGH)
        self.spi.close()
        self.reg_dr = 0
        self.reg_mode = 0
        # HRSC ROM values
        self.sensor_rom = [0] * 512 # 512 bytes of EEPROM
        self.read_eeprom()
        self.PCompr = 0.0
        self.raw_auto_zero_pressure = 0.0
    
    def read_eeprom(self):
        #print "Loading EEPROM data from sensor",
        #print ".",
        # Assert EEPROM SS to L, Deassert ADC SS to H, Set mode 0 or mode 4
        self.spi.open(self.spi_bus, 1)
        self.spi.max_speed_hz = self.spi_max_speed_hz
        if self.force_spi_mode: self.spi.mode = self.EE_spi_mode
        if (self.alt_spi_cs1 >= 0): GPIO.setup(self.alt_spi_cs1, GPIO.OUT, initial = GPIO.LOW)
        if (self.alt_spi_cs0 >= 0): GPIO.setup(self.alt_spi_cs0, GPIO.OUT, initial = GPIO.HIGH)
        for i in range (0,256):
            self.sensor_rom[i] = self.spi.xfer([HRSC_EAD_EEPROM_LSB, i, 0x00], self.spi_speed_hz)[2] # Read low page
#            print "%c" % (self.sensor_rom[i]),
        for i in range (0,256):
            self.sensor_rom[i+256] = self.spi.xfer([HRSC_EAD_EEPROM_MSB, i, 0x00], self.spi_speed_hz)[2] # Read high page
        # Clear EEPROM SS , set mode 1 for ADC
        self.spi.close()
       
    def reset(self):
        # Clear EEPROM SS , assert ADC SS, set mode 1 for ADC
        self.spi.open(self.spi_bus, 0)
        self.spi.max_speed_hz = self.spi_max_speed_hz
        if self.force_spi_mode: self.spi.mode = 0b01
        if (self.alt_spi_cs0 >= 0): GPIO.setup(self.alt_spi_cs0, GPIO.OUT, initial = GPIO.LOW)
        if (self.alt_spi_cs1 >= 0): GPIO.setup(self.alt_spi_cs1, GPIO.OUT, initial = GPIO.HIGH)
        self.bytewr = 3
        self.regaddr = 0
        # Reset command
        test = self.spi.xfer([HRSC_ADC_RESET], self.spi_speed_hz)
        self.spi.close()
        
    def adc_configure(self):
        # Clear EEPROM SS , assert ADC SS, set mode 1 for ADC
        self.spi.open(self.spi_bus, 0)
        self.spi.max_speed_hz = self.spi_max_speed_hz
        if self.force_spi_mode: self.spi.mode = 0b01
        if (self.alt_spi_cs0 >= 0): GPIO.setup(self.alt_spi_cs0, GPIO.OUT, initial = GPIO.LOW)
        if (self.alt_spi_cs1 >= 0): GPIO.setup(self.alt_spi_cs1, GPIO.OUT, initial = GPIO.HIGH)
        self.bytewr = 3
        self.regaddr = 0
        # Write configuration registers from ROM
        #print ("%02X" % self.sensor_rom[61]),
        #print ("%02X" % self.sensor_rom[63]),
        #print ("%02X" % self.sensor_rom[65]),
        #print ("%02X" % self.sensor_rom[67]),
        test = self.spi.xfer2([HRSC_ADC_WREG|self.regaddr << 3|self.bytewr & 0x03, self.sensor_rom[61], self.sensor_rom[63], self.sensor_rom[65], self.sensor_rom[67] ], self.spi_speed_hz)        
        self.spi.close()

    def conv_to_float(self, byte1, byte2, byte3, byte4):
        temp = struct.pack("BBBB", byte1,byte2,byte3,byte4)
        output = struct.unpack("<f", temp)[0]
        return output
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

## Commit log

2020-03-25 Added pressure figure
2020-03-30 Preliminary support of 2 valves
2020-03-31 Attempt to take into account pressure
2020-04-06 Updated for new valves
2020-04-07 Minor updates and changed LED GPIO
2020-04-07 Added preliminary support of a 2nd BAR02 sensor and GUI updates
2020-04-08 Enabled back PEEP_reached and added the display of valves input
2020-04-10 Added the code used to test the differential pressure sensor
2020-04-10 Minor updates in flow computation
2020-04-12 Updated flow and other minor updates
2020-04-12 Updated flow
2020-04-13 Merged flow code in main.py
2020-04-14 Corrected diameter in Venturi and added temperature0 in log file
    [gui.py, main.py]
2020-04-15 Added preliminary support of 3rd Honeywell RSC for O2 flow
2020-04-16 Honeywell RSC temperature is now measured at each loop
2020-04-17 Added 3rd valve to try to support a depressor for expiration
2020-04-18 Updates and corrections for Honeywell RSC
    [main.py, rsc.py]
2020-04-18 Improved compatibility with Honeywell RSC sensors with different units
2020-04-19 Added preliminary support of O2 valve and an additional filter for flow
2020-04-19 Added preliminary support of Honeywell HSC in replacement of the 2 Bar02
    [gui.py, hsc.py, main.py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]
2020-04-20 Updated filter for flow and preliminary O2:Air mix mode
2020-04-21 Added option to use hardware PWM for air and O2 valves and preliminary support of a second Honeywell HSC
2020-04-22 Updated flow control
2020-04-22 Added preliminary flow limitation when reaching Ppeak and preliminary support of a proportional expiration valve
2020-04-23 Updated flow limitation
2020-04-23 Updated preliminary support of a proportional expiration valve
2020-04-28 Updated Honeywell HSC support and new expiration valve
2020-04-29 Updated Honeywell RSC support and updated flow control
2020-04-30 Updated flow control and assistance mode
2020-05-01 Updated flow control, added parameters and updated GUI
2020-05-01 Added flow_thresh parameter
2020-05-04 Corrected GUI bug and updated some parameters
    [gui.py, main.py]
2020-05-06 Updated buzzer with pigpio and updated alarms
    [gui.py, main.py]
2020-05-17 Replaced or changed Flow A, Flow O, I:E, FEA, FEO with Flow, O2, I:E (in %), FE, OE parameters
    [gui.py, main.py]
2020-05-17 Corrections for the parameters that changed
    [main.py]
2020-05-17 Ensure the proportion of O2 is always correct even in case flow needs to be reduced due to too high pressure
    [main.py]
2020-05-18 Corrections for the ramp
    [main.py]
2020-05-19 Swapped inspiration and expiration pressure sensors
    [main.py]
2020-05-25 Dividing file types
    [Adapter_12x22mm_45deg.stl, Adapter_12x22mm_v2.stl, Orifice_3.50mm.stl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]
2020-05-29 Corrected potential divisions by 0
    [main.py]
